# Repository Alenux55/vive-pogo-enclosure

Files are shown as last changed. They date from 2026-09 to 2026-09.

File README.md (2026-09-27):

# VIVE pogo enclosure

Prototype enclosure for the VIVE pogo PCB.

September 27 update: the rear contact opening now accommodates the R2 board's three 2 mm pads at 3 mm pitch. Its native cylinder/bridge construction and spreadsheet controls are preserved. Use the current STEP/STL exports; the saved slicer 3MF has older geometry and must have its rear-shell object replaced and re-sliced. The front shell is geometrically unchanged. Detailed measurements are in `docs/validation/three-contact-update.json`.

## Files

- `cad/Vive-Shoe.FCStd`: authoritative editable FreeCAD assembly, including feature history and embedded controller/PCBA references. Open with FreeCAD 1.1 or later. Some imported reference geometry is a fixed solid rather than a sketch-based model.
- `exports/print/`: upright shell STEP and STL files, positioned with their lowest point at Z=0. Prefer STEP for OrcaSlicer. `PCBA-flat-no-pins.step` is only a printable fit mockup, with underside projections removed; it is not a fabrication model.
- `exports/assembly/`: shells and complete assembly in their original assembly coordinates.
- `references/pcb/`: September 24 PCB STEP snapshot used to build the enclosure. The PCB's electrical source and manufacturing releases belong in the separate `vive-pogo` repository.
- `docs/`: design notes and validation evidence.
- `scripts/export_shells.py`: regenerate shell STEP/STL files from the saved FreeCAD model.

## Editing and exporting

Edit the native document and save before regenerating exports. The export script reads the saved file; it does not rebuild the model from scratch. Historical one-off migration scripts are deliberately omitted because they depend on older versions and machine-specific paths.

The document uses FreeCAD's native Part-workbench constructive-solid-geometry workflow. This is intentional: the shoe is driven by shared lofts and boolean tools before branching into two printable solids. The editable source objects are preserved rather than collapsed into final imported shapes.

Expand the `VIVE shoe assembly` container to find six ordered groups: editing guide and parameters, reference geometry, master construction, front-shell construction, rear-shell construction, and export outputs. Start with the in-model `READ ME - editing guide`, then edit the `00 Dimensions - edit column B, then recompute` spreadsheet for dimension-driven values or expand a construction group to edit its sketches and primitive features directly. Cuts, fusions, and common operations are derived results; edit their named input tools to change the geometry. Disconnected historical construction branches are kept in Git history rather than in the active CAD document.

Each shell branch includes `Round exposed outer rim - 0.8 mm`. It rounds only the exterior upper edge; the inner controller-contact rim and the shell mating plane are unchanged. The front branch ends with `Cut 45-degree screw-head roofs`, using two editable sketches to turn the unsupported upper arcs of the horizontal head recesses into printable teardrop roofs. The rear branch includes `Bevel rear PCB ceiling edges - 1.0 mm`, an editable 45-degree chamfer that reduces the flat supported ceiling around the connector opening without changing the PCB bosses or seating faces.

Run `scripts/export_shells.py` using FreeCAD's Python environment, or execute it from FreeCAD's Python console with `exec(compile(open(path).read(), path, 'exec'), {'__file__': path, '__name__': '__main__'})`, where `path` is the absolute script path. It resolves repository paths automatically. It exports only the two shells; re-export the full assembly from FreeCAD when reference components change. The PCB mockup is a preserved snapshot, not regenerated by this script.

Commit native CAD and matching exports together. Keep the current files in these folders; use Git history and release tags for future revisions rather than duplicating entire version folders.

## Printing and assembly

The supplied print orientation is upright, with the shoe bottom on the bed. The geometry includes 45-degree roofs over the front shell's horizontal screw-head recesses and a 1 mm rear-pocket ceiling bevel to reduce abrupt overhangs, but the PCB boss and seating faces deliberately remain flat. Inspect supports in the slicer, especially those functional faces and the remaining screw-shank overhangs; protect the controller-facing fit surface from support scarring. These are prototype exports, not a validated production print profile.

With Bambu Support for PLA/PETG, use ordinary model filament for the support base and select the support material only for the support/raft interface. This keeps the flat functional faces well supported while avoiding unnecessary filament changes throughout the entire support tree. Check the sliced preview before printing because automatic support placement depends on the selected profile and threshold.

Hardware baseline: four McMaster 96817A840 M2 x 4 screws per shoe. Nominal pilot diameter is 1.6 mm. Verify screw engagement and head clearance in the physical assembly.

## Fit status

The September 25 released PCB copy checked against the enclosure matched its board, connector and resistor geometry. No solid shell or PCB-screw intersections were found. The released contact pads are 2 mm diameter at 3 mm pitch and match the opening.

The connector touches the rear shell nominally. The sampled insertion path has a minimum clearance of about 0.014 mm; this is not a continuous-path or manufacturing-tolerance guarantee. The fabrication stack reports 0.89 mm overall versus the STEP's 0.8 mm substrate. A printed PCB mockup fitted successfully according to the user; assembled hardware still needs a physical fit and charging test.

See `docs/design-notes.md` and `docs/validation/` for the original design checks. Those JSON files predate the September 25 release review.

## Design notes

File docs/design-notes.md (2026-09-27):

# Vive shoe — PCB fit and enclosure changes

## September 27 — three-contact R2 PCB

The current reference snapshot is `VIVE Pogo Board R2.0 STEP - No Variant (2026-09-27 02-24).step`. The three underside targets are 2 mm diameter, at board coordinates X=10.8 mm and Y=2, 5, 8 mm. Registration retains the existing connector alignment and 3-degree board tilt.

The rear shell's native `ContactSlot` capsule is extended to cover the three targets. Its two cylinders and bridge remain editable, driven by `ContactRowX`, `ContactRowFrontY`, `ContactRowRearY`, and `SlotWidth` in the Dimensions spreadsheet. The original ordered model groups remain intact. The imported PCB/copper references are refreshed from R2, and the reference contact markers now show all three pads.

Use the regenerated rear-shell STEP/STL for the next print. The existing slicer 3MF still contains the older shell geometry; replace that object and re-slice before using it. The dock's earlier two-contact coordinate table also needs revision during dock hardware/mechanical integration.

See `validation/three-contact-update.json` for the geometric checks and the transformed contact centres.

## Earlier fit and printability history

Source snapshot: vive-pogo-source.step, copied from E:/Documents/GitHub/vive-pogo/vive-pogo.step (modified September 24, 2026, 22:56:51). The PCB repository was not edited.

Updated PCB is 21.5 x 10 x 0.8 mm, with 1 mm corner radii. The new resistor, copper and pads are included. Registration uses the connector's placement, preserving the corrected orientation toward the wrist strap and the existing 3-degree tilt.

The rear pocket's two closed corners now have 1.2 mm radii, adding a modest amount of plastic while retaining clearance around the 1 mm board corners. Front entrance corners stay open for insertion. The new corner operations are native editable Part cuts in the FreeCAD tree (corner squares/arcs and rounded pocket tools). The pogo slot moved to match the new 2 mm pads at 3 mm spacing; it remains entirely in the rear shell.

Both shells clear the seated board, connector, copper and added resistor in the model. The PCB screw geometry is checked against the new assembly. Hardware remains four McMaster 96817A840 M2 x 4 screws per shoe. Nominal floor remains 0.60 mm.

Sampled insertion check: twelve positions with the PCBA 0.4 mm below final seating height clear the shell. Smallest sampled clearance is approximately 0.014 mm. This is a tight prototype fit, not a continuous path proof or allowance for all manufacturing tolerances. Physically test insertion and screw-head protrusion before finalizing the dock.

September 25 printability update: both shells now have editable 0.8 mm fillets on the exposed outer upper rim. The inner controller-contact rim, shell mating plane and bed-contact edge remain unchanged. The front shell's horizontal screw-head recesses now have native sketch-and-extrusion 45-degree roofs, reducing non-bed downward-facing area above 45 degrees by approximately 39.2 percent. Their circular lower clearance is retained. The rear shell also has a native 1.0 mm chamfer around the connector-side edges of the PCB-cavity ceiling. This reduced the rear STL's downward-facing area above 45 degrees from approximately 483.5 to 452.9 mm2; excluding the bed-contact underside, the reduction is approximately 20.6 percent. The flat PCB boss and seating faces remain unchanged so their functional datums are preserved.

Both shells therefore require reprinting to evaluate the complete update. Use the corresponding `FrontShell-UPRIGHT` and `RearShell-UPRIGHT` STEP files. When Bambu Support for PLA/PETG is available, use it for interface layers only and keep ordinary model filament for the support base. These enclosure checks do not constitute electrical or PCB fabrication approval.

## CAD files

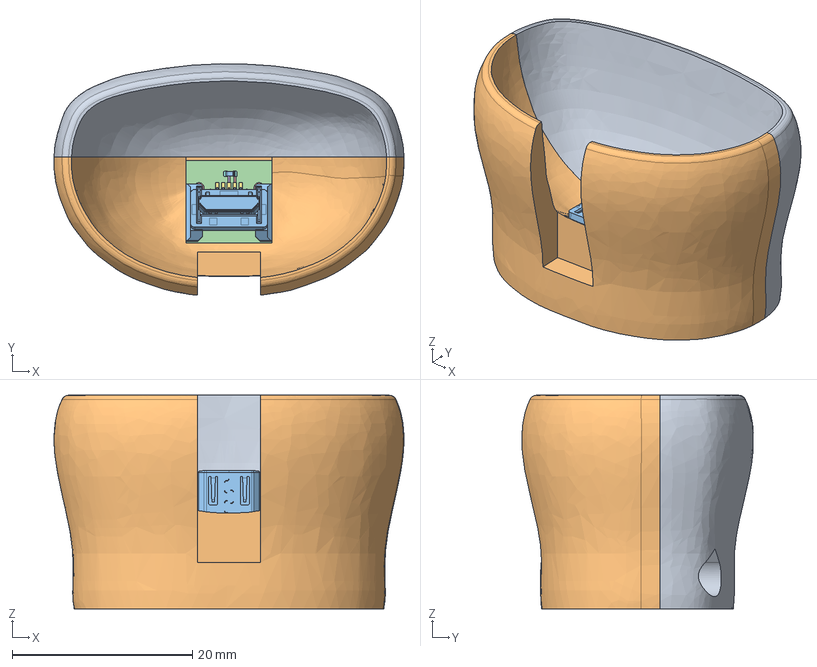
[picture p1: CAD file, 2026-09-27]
exports/assembly/Vive-Shoe-assembly.step
38.8 x 25.7 x 23.7 mm

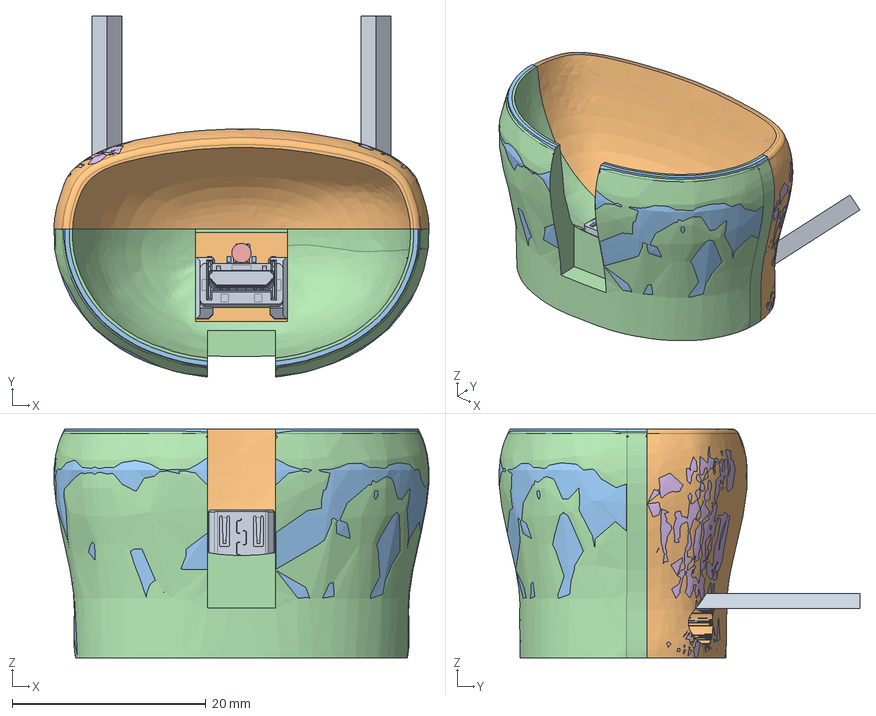
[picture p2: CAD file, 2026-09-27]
cad/Vive-Shoe.FCStd
38.8 x 37.3 x 23.7 mm
Actual ZX80-B-5S connector x 3
Actual PCB substrate - 0.8 mm in STEP x 3
Actual copper, pads and plated holes x 3
ActualResistor x 3
ContactTarget2 x 4
15 Round exposed outer rim - 0.8 mm x 2
16.3 Extrude left head-roof relief x 2
16.4 Extrude right head-roof relief x 2
16.5 Fuse screw-head roof reliefs x 2
16 Cut 45-degree screw-head roofs x 4
14 Bevel rear PCB ceiling edges - 1.0 mm x 2
15 Round exposed outer rim - 0.8 mm001 x 4

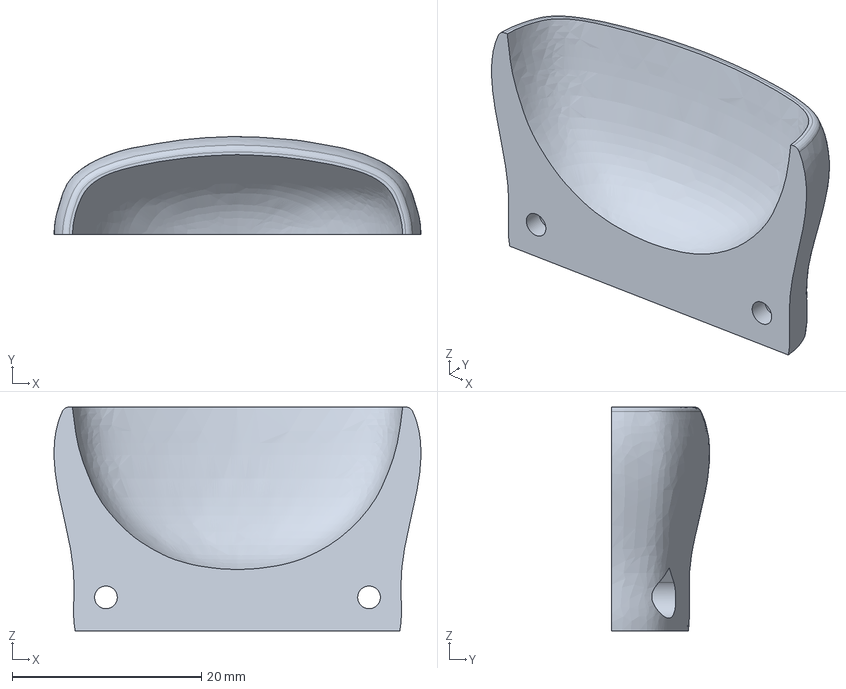
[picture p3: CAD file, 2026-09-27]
exports/assembly/FrontShell.step
38.8 x 10.4 x 23.7 mm

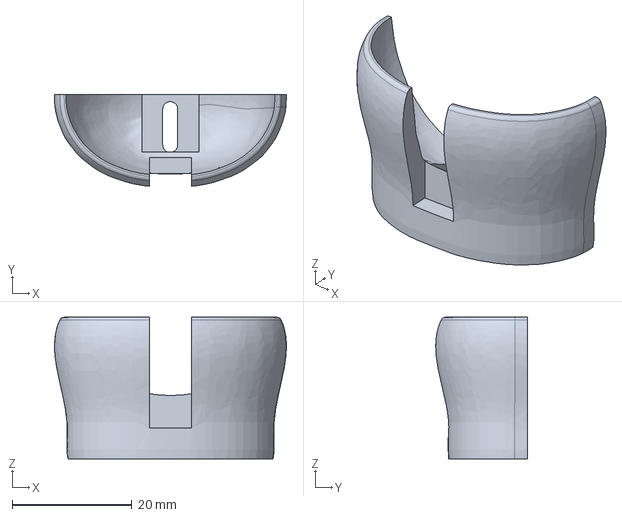
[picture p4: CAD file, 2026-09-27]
exports/print/RearShell-UPRIGHT.step
38.8 x 15.3 x 23.7 mm

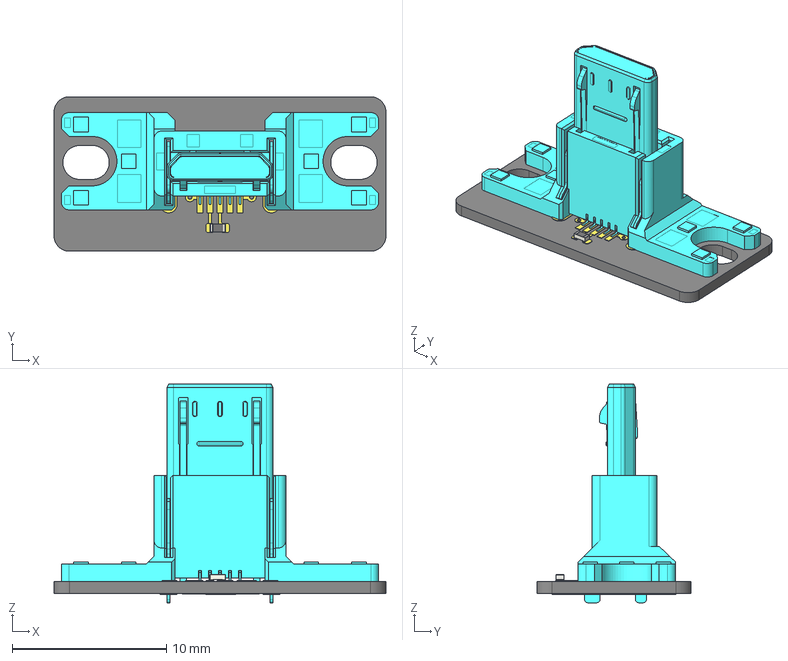
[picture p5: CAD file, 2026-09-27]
references/pcb/vive-pogo-source.step
21.5 x 10.0 x 14.2 mm
ZX80-B-5S
R_0402_1005Metric
vive-pogo_copper
vive-pogo_pad
vive-pogo_via
vive-pogo_PCB

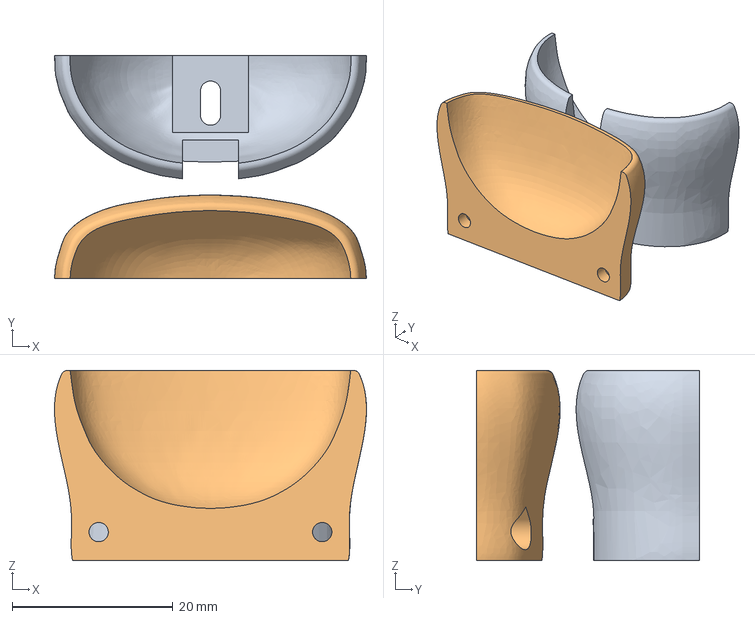
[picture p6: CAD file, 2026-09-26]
exports/print/vive-pogo-enclosure.3mf
38.8 x 27.7 x 23.7 mm
RearShell-UPRIGHT.stl
FrontShell-UPRIGHT.stl

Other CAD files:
exports/assembly/RearShell.step
exports/print/FrontShell-UPRIGHT.step
exports/print/PCBA-flat-no-pins.step
exports/print/FrontShell-UPRIGHT.stl
exports/print/RearShell-UPRIGHT.stl

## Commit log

2026-09-26 Removed references to V17, which are kind of meaningless now
    [Vive-Shoe-V17-assembly.step, Vive-Shoe-assembly.step]
2026-09-26 Updated the FreeCAD model tree to show all edits
    [Vive-Shoe.FCStd]
2026-09-26 Improving printability
    [FrontShell-UPRIGHT.step, FrontShell-UPRIGHT.stl, FrontShell.step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]
2026-09-27 Updated based on pogo board changes
    [FrontShell-UPRIGHT.step, FrontShell-UPRIGHT.stl, FrontShell.step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]
